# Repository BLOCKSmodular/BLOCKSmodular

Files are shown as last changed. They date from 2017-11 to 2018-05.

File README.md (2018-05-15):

# BLOCKSmodular
**WORK IN PROGRESS**  
This is work in progress. Please use it at your own risk.  

BLOCKSmodularはROLI BLOCKSとモジュラーシンセサイザーとを連携させることからはじまった、新しい音楽インターフェース/音楽表現を考えるプロジェクトです。  
開発はオープンソースで進められており、ソースコード、筐体や基板設計データをライセンスの範囲内において自由に利用できます。  
[プロジェクトサイト](https://blocksmodular.github.io/)にはBLOCKSmodularを使用したパフォーマンス映像などもアップされています。  

## Feature
- 8ch CV output  
- 4ch Gate output  
- 2ch Audio output  

## LICENSE
GPL v3

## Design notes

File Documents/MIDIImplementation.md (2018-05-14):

# MIDI Implementation
##モード切り替え
| Mode | MIDI CC | Value | MIDI Channel |
| :--- | :--- | :---- | :--- |
| Init | 1 | 0 | 16(MIDI: 0xBF) |
| Granular synthesis | 1 | 1 | 16(MIDI: 0xBF) |
| Sample playback | 1 | 2 | 16(MIDI: 0xBF) |
| Karplus strong | 1 | 3 | 16(MIDI: 0xBF) |
| Logistic map | 1 | 4 | 16(MIDI: 0xBF) |
| Sine circle map | 1 | 5 | 16(MIDI: 0xBF) |
| Morph looper | 1 | 6 | 16(MIDI: 0xBF) |
| Microtonal | 1 | 7 | 16(MIDI: 0xBF) |
| Euclid | 1 | 8 | 16(MIDI: 0xBF) |

## モード詳細
### Granular synthesis
| Description | MIDI CC | Value | MIDI Channel |
| :--- | :--- | :---- | :--- |
| X: Sample start position  | 1, 2 | 14bit | 1~4 |
| Y : Grain size | 3, 4 | 14bit | 1~4 |
| Z : Window function shape | 5, 6 | 14bit | 1~4 |

### Sample playback
| Description | MIDI CC | Value | MIDI Channel |
| :--- | :--- | :--- | :--- |
| Transpose(Play/Stop) | 1 | 0(stop)/127(play) | 1~4 |

### Karplus strong
| Description | MIDI CC | Value | MIDI Channel |
| :--- | :--- | :---- | :--- |
| Distance: Pitch | 1, 2 | 14bit | 1~4 |
| Z(Pressure): Decay | 3, 4 | 14bit | 1~4 |
| Touch start: trigger | 5 | 127 | 1~4 |

### Logistic map
| Description | MIDI CC | Value | MIDI Channel |
| :--- | :--- | :---- | :--- |
| Distance: Logistic map alpha | 1, 2 | 14bit | 1 |
| Z(Pressure): Volume | 3, 4 | 14bit | 1 |
| Distance: Sine circle map alpha | 1, 2 | 14bit | 2 |
| Z(Pressure): Volume | 3, 4 | 14bit | 2 |

### Morph looper
| Description | MIDI CC | Value | MIDI Channel |
| :--- | :--- | :--- | :--- |
| Rec | 1 | 0(End)/127(Begin) | 1, 2 |
| Play | 2 | 0(Stop)/127(Play) | 1, 2 |
| X | 3, 4 | 14bit | 1, 2 |
| Y | 5, 6 | 14bit | 1, 2 |
| Z | 7, 8 | 14bit | 1, 2 |

*Note*
| Description | Note number | Value | MIDI Channel |
| :--- | :--- | :--- | :--- |
| Clear | 1 | Note on | 1, 2 |

### Microtonal
| Description | MIDI CC | Value | MIDI Channel |
| :--- | :--- | :---- | :--- |
| Distance | 1, 2 | 14bit | 1~4 |
| Z | 3, 4 | 14bit | 1~4 |

### Euclid sequence

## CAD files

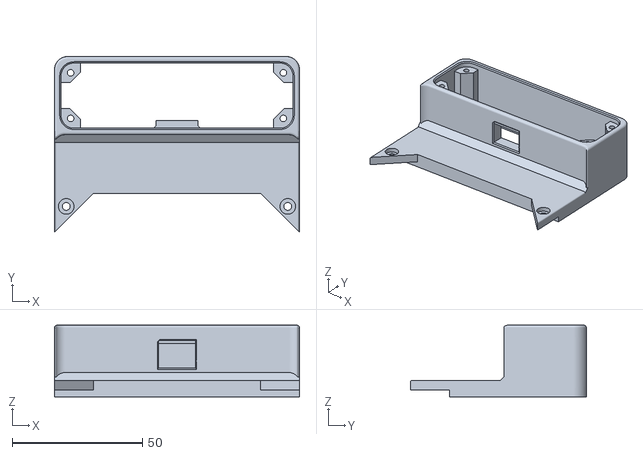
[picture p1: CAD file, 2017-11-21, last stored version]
Prototype/v0.5.0/body/blocksmodularv3.0 v2_top v2_2.stl
94.0 x 67.5 x 27.5

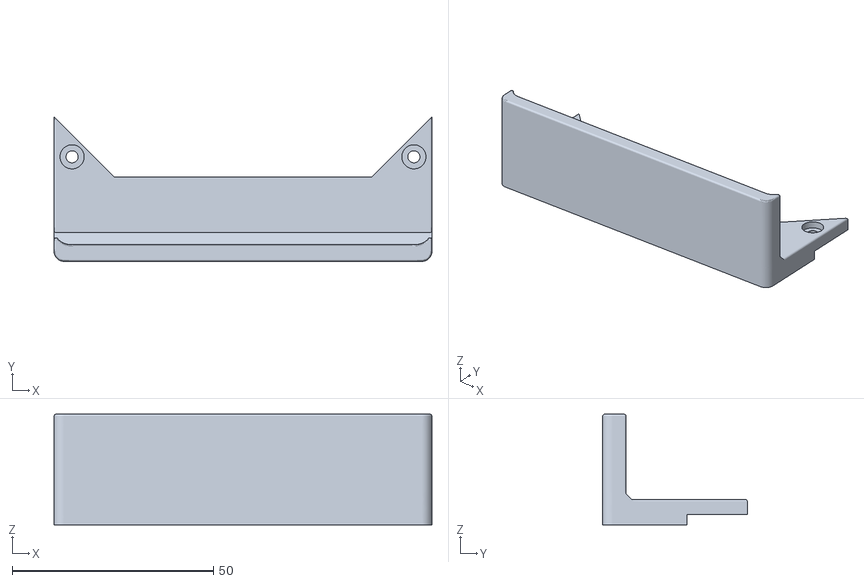
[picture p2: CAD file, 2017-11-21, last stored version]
Prototype/v0.5.0/body/blocksmodularv3.0 v2_bottom v2 v1.stl
94.0 x 36.0 x 27.5

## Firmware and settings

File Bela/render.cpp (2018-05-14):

/*
 BLOCKSmodular ver0.7.0
 render.cpp for BLOCKSmodular
 Created by Akiyuki Okayasu
 License: GPLv3
 */
#include <Bela.h>
#include <Midi.h>
#include <stdlib.h>
#include <cmath>
#include <atomic>
#include <vector>
#include <random>
#include <SampleBuffer.h>
#include <Util.h>
#include <GranularSynth.h>
#include <LogisticMap.h>
#include <SineCircleMap.h>
#include <KarplusStrong.h>

enum class ModeList{
    init = 0,
    Granular,
    SamplePlay,
    Karplus,
    Logistic,
    SineCircle,
    MorphLooper,
    Microtonal,
    Euclid
};

static constexpr int NUMCVOUT = 8;
static constexpr int NUMSAMPLEPLAYBUFFER = 4;
static constexpr int NUMKARPLUSVOICE = 4;
static constexpr int NUMMICROTONALVOICE = 4;
Midi midi;
ModeList mode;
const char *gMidiPort0 = "hw:1,0,0";

LogisticMap logisticOsc;
HighResolutionControlChange	lgst_alpha;
HighResolutionControlChange lgst_gain;
SineCircleMap sineCircleOsc;
HighResolutionControlChange sineCircle_k;
HighResolutionControlChange sineCircle_gain;
GranularSynth granular;
HighResolutionControlChange gr_Position[2];
HighResolutionControlChange gr_GrainSize[2];
HighResolutionControlChange gr_WindowShape[2];
HighResolutionControlChange microtone_Distance[NUMMICROTONALVOICE];
HighResolutionControlChange microtone_Pressure[NUMMICROTONALVOICE];
StereoBuffer* samplePlay_buffer;
bool samplePlay_isPlaying[NUMSAMPLEPLAYBUFFER]{false, false, false, false};
KarplusStrong karplus[NUMKARPLUSVOICE];
HighResolutionControlChange kp_pitch[NUMKARPLUSVOICE];
HighResolutionControlChange kp_decay[NUMKARPLUSVOICE];
Smoothing CVSmooth[NUMCVOUT];

void midiMessageCallback(MidiChannelMessage message, void *arg)
{
    const int channel = message.getChannel();//MIDIChannel(0~15)
    if(message.getType() == kmmControlChange)//MIDI CC
    {
        const int controlNum = message.getDataByte(0);
        const int value = message.getDataByte(1);
        //std::cout<<channel<<", "<<controlNum<<", "<<value<<std::endl;
        
        switch(mode) {
            case ModeList::init: {
                std::cout<<"mode init..."<<std::endl;
                break;
            }
            case ModeList::Granular: {
                if(channel >= 2)
                {
                    break;
                }
                
                if(controlNum == 1 || controlNum == 2) {
                    bool isUpeerByte{controlNum == 1};
                    gr_Position[channel].set(value, isUpeerByte);
                    if(gr_Position[channel].update()) granular.setBufferPosition(gr_Position[channel].get(), channel);
                }
                
                if(controlNum == 3 || controlNum == 4) {
                    bool isUpeerByte{controlNum == 3};
                    gr_GrainSize[channel].set(value, isUpeerByte);
                    if(gr_GrainSize[channel].update()) granular.setGrainSize(gr_GrainSize[channel].get(), channel);
                }
                
                if(controlNum == 5 || controlNum == 6) {
                    bool isUpeerByte{controlNum == 5};
                    gr_WindowShape[channel].set(value, isUpeerByte);
                    if(gr_WindowShape[channel].update()) {
                        float v = gr_WindowShape[channel].get() * 2.0f;
                        granular.setWindowShape(v * 4.0f, channel);
                        granular.setDensity((v * v * v), channel);
                    }
                }
                
                break;
            }
            case ModeList::SamplePlay: {
                if(channel >= NUMSAMPLEPLAYBUFFER)
                {
                    break;
                }
                
                if(controlNum == 1) {
                    if(value == 127) {
                        samplePlay_buffer[channel].setReadIter(0);
                        samplePlay_isPlaying[channel] = true;
                    }
                }
                
                break;
            }
            case ModeList::Karplus: {
                if(channel >= NUMKARPLUSVOICE)
                {
                    break;
                }
                
                if(controlNum == 1 || controlNum == 2) {
                    bool isUpeerByte{controlNum == 1};
                    kp_pitch[channel].set(value, isUpeerByte);
                    if(kp_pitch[channel].update()) {
                        const float p = kp_pitch[channel].get() * 40.0f + 40.0f;//40Hz~80Hz
                        karplus[channel].setFreq(p);
                    }
                }
                
                if(controlNum == 3 || controlNum == 4) {
                    bool isUpeerByte{controlNum == 3};
                    kp_decay[channel].set(value, isUpeerByte);
                    if(kp_decay[channel].update()) karplus[channel].setDecay(kp_decay[channel].get());
                }
                
                if(controlNum == 5 && value == 127) {
                    karplus[channel].trigger();
                }
                
                break;
            }
            case ModeList::Logistic: {
                if(channel == 0) {
                    if(controlNum == 1 || controlNum == 2) {
                        bool isUpeerByte{controlNum == 1};
                        lgst_alpha.set(value, isUpeerByte);
                        if(lgst_alpha.update()) logisticOsc.setAlpha(lgst_alpha.get() * 0.5f + 3.490f);
                    }
                    
                    if(controlNum == 3 || controlNum == 4) {
                        bool isUpeerByte{controlNum == 3};
                        lgst_gain.set(value, isUpeerByte);
                        if(lgst_gain.update()) logisticOsc.setGain(lgst_gain.get());
                    }
                }
                else if(channel == 1) {
                    if(controlNum == 1 || controlNum == 2) {
                        bool isUpeerByte{controlNum == 1};
                        sineCircle_k.set(value, isUpeerByte);
                        if(sineCircle_k.update()) sineCircleOsc.setK(sineCircle_k.get() * 0.2f + 1.0f);
                    }
                    
                    if(controlNum == 3 || controlNum == 4) {
                        bool isUpeerByte{controlNum == 3};
                        sineCircle_gain.set(value, isUpeerByte);
                        if(sineCircle_gain.update()) sineCircleOsc.setGain(sineCircle_gain.get());
                    }
                }
                break;
            }
            case ModeList::SineCircle: {
                //TODO SineCircleMapモードの実装
                break;
            }
            case ModeList::MorphLooper: {
                break;
            }
            case ModeList::Microtonal: {
                if(channel >= NUMMICROTONALVOICE) {
                    std::cout<<"MIDI: Invalid voice number"<<std::endl;
                    break;
                }
                
                if(controlNum == 1 || controlNum == 2) {
                    bool isUpeerByte{controlNum == 1};
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

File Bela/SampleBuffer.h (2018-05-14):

/*
 SampleBuffer.h for BLOCKSmodular
 Created by Akiyuki Okayasu
 License: GPLv3
 */

#ifndef SAMPLEBUFFER_H_
#define SAMPLEBUFFER_H_

#include <Bela.h>
#include <sndfile.h>// to load audio files
#include <string>
#include <iostream>
#include <cstdlib>
#include <vector>
#include <Util.h>
#include <atomic>

class MonoBuffer {
public:
    MonoBuffer(const int size, bool loopPlaying = false, bool loopRecording = false)
    :readLoop(loopPlaying), writeLoop(loopRecording)
    {
        buffer.resize(size);
        bufferSize = size;
    }
    
    ~MonoBuffer(){}
    
    void resize(const int size)
    {
        buffer.resize(size, 0.0f);
        bufferSize = size;
    }
    
    void nextBlock(float* bufferToWrite, const int blockSize)
    {
        for(int i = 0; i < blockSize; ++i)
        {
            bufferToWrite[i] += buffer[readIter];
            addReadIter(1);
        }
    }
    
    const float* getReadPtr()
    {
        return buffer.data();
    }
    
    float* getWritePtr()
    {
        return buffer.data();
    }
    
    int getSize()
    {
        return bufferSize;
    }
    
    const unsigned int getWriteIter()
    {
        return writeIter;
    }
    
    const unsigned int getReadIter()
    {
        return readIter;
    }
    
    void readNext(float& value)
    {
        if(readIter < bufferSize)
        {
            value += buffer[readIter];
            addReadIter(1);
        }
    }
    
    void writeNext(float& value)
    {
        buffer[readIter] = value;
        addWriteIter(1);
    }
    
    void addReadIter(const unsigned int add)
    {
        if(readIter + add >= bufferSize && !readLoop) {
            readIter = bufferSize;
            return;
        }
        
        readIter += add;
        if(readIter >= bufferSize) {
            readIter -= bufferSize;
        }
    }
    
    void addWriteIter(const unsigned int add)
    {
        if(writeIter + add >= bufferSize && !writeLoop) {
            writeIter = bufferSize;
            return;
        }
        
        writeIter += add;
        if(writeIter >= bufferSize) {
            writeIter -= bufferSize;
        }
    }
    
    void setReadIter(const unsigned int itr) {
        if(itr < buffer.size()) {
            readIter = itr;
        }
        else{
            std::cout<<"MonoBuffer-setReadIter(): Invalid iterater"<<std::endl;
        }
    }
    
    void loadSampleFile(std::string file)
    {
        SNDFILE *sndfile ;
        SF_INFO sfinfo ;
        sfinfo.format = 0;
        if (!(sndfile = sf_open (file.c_str(), SFM_READ, &sfinfo))) {
            std::cout << "Couldn't open file " << file << ": " << sf_strerror(sndfile) << std::endl;
            return;
        }
        
        int numChannelsInFile = sfinfo.channels;
        
        if(numChannelsInFile != 1)//1chのファイルのみ許可
        {
            std::cout << "Error: " << file << " doesn't contain requested channel" << std::endl;
            return;
        }
        
        const int frameLen = getNumFrames(file);
        if(buffer.size() < frameLen) {
            std::cout << "Warning: MonoBuffer class was resized!!!" << std::endl;
            buffer.resize(frameLen, 0.0f);
            bufferSize = frameLen;
        }
        
        sf_seek(sndfile,0,SEEK_SET);
        float* tempBuf = new float[frameLen*numChannelsInFile];
        int subformat = sfinfo.format & SF_FORMAT_SUBMASK;
        int readcount = sf_read_float(sndfile, tempBuf, frameLen*getNumChannels(file)); //FIXME
        
        // Pad with zeros in case we couldn't read whole file
        for(int k = readcount; k <frameLen*numChannelsInFile; k++)
            tempBuf[k] = 0;
        
        if (subformat == SF_FORMAT_FLOAT || subformat == SF_FORMAT_DOUBLE)
        {
            double	scale ;
            int 	m ;
            
            sf_command (sndfile, SFC_CALC_SIGNAL_MAX, &scale, sizeof (scale)) ;
            if (scale < 1e-10)
                scale = 1.0 ;
            else
                scale = 32700.0 / scale ;
            std::cout << "File samples scale = " << scale << std::endl;
            
            for (m = 0; m < frameLen; m++)
                tempBuf[m] *= scale;
        }
        
        for(int n=0;n<frameLen;n++)
        {
            buffer[n] = tempBuf[n*numChannelsInFile];
            /*Streeo buffer and Stereo file
             buffer[n][0] = tempBuf[n*numChannelsInFile + 0];
             buffer[n][1] = tempBuf[n*numChannelsInFile + 1];
             */
        }
        
        sf_close(sndfile);
    }
    
private:
    std::vector<float> buffer;
    std::atomic<unsigned int> readIter{0};
    std::atomic<unsigned int> writeIter{0};
    unsigned int bufferSize;
    bool readLoop;
    bool writeLoop;
};
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

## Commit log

2017-10-16 [add] Maxパッチを追加
2017-10-17 筐体データ
2017-10-17 Initialize Arduino - convert serial values to CV - convert PWM to Analog signal
2017-10-20 [remove] OSC送信部分を削除
    Raspberry piへOSCを送ることを想定していたが、しばらく着手しないので削除。
    他オブジェクトの整列。コメント追加も適宜行なっている。
2017-10-20 [remove] Seaboard BLOCKからMIDI受信部分を削除
    トランスポートの管理、シリアル通信、LightpadのUI部分をきちんと詰めてから、Seaboard BLOCKに着手することにする
2017-10-20 [update] シリアル通信部分を改良
    CV出力ごとにセパレータをつけて送っていたが、通信量多くなり、順番の保証もされない懸念があった。
    全てのCV出力のデータを同時に送信することで通信量削減と順番の保証をした。
    具体的には
    CV1前半8bit, 後半8bit, CV2前半8bit, 後半8bit, CV3前半8bit, 後半8bit, CV4前半8bit, 後半8bit
    のリストを送信している。
2017-10-20 筐体データ修正
2017-10-22 [update] シリアル通信の仕様を改善
    CV出力を8つに増やした。
    シリアルで送信するリストのプリフィックスはhとした。
    送信するリストはこのようになった。
    [h, cv1上位8bit, cv1下位8bit, cv2上位8bit, cv2下位8bit, cv3上位8bit, cv3下位8bit, cv4上位8bit, cv4下位8bit, cv5上位8bit, cv5下位8bit, cv6上位8bit, cv6下位8bit, cv7上位8bit, cv7下位8bit, cv8上位8bit, cv8下位8bit]
    またシリアルのデータ転送レートを115200bpsに変更。
2017-10-25 [update] blocks.looper~の代わりにbuffer~でLightpadの動きの記録をさせる
    blocks.looper~を複数個同時使用すると不安定になっていたのでbuffer~で同じ機能を作る
2017-10-25 [remove] ルーパー機能の置き換えに伴ってこれまでの制御部分を削除
2017-10-29 [add] XYZの動きを記録しループするLittlefootのプログラムを追加
2017-10-30 [update] MaxパッチにRec開始を伝えるためのフラグ機能を整理
2017-10-30 [add] コメントを追加
    state(セッションビュー画面/XYZパッドなどの状態)に関するコメントを追加。
2017-10-30 [add] 録音/再生状態による条件分岐を追加
    トランスポート管理用の条件分岐。
2017-10-30 [add] MIDI受信ハンドラを追加
    MIDI受信するハンドラを準備しただけ。
    MIDI受信の内容によってrecクリアなどの機能を割り当てる予定。
2017-10-30 [update] Maxパッチの軽微な変更。
    オブジェクトの位置調整などで変更が加えられてしまったのでコミット。
    Littlefootプログラムが落ち着いたらMaxパッチも大規模な変更を加える予定なので、今回の変更に意味はない。
2017-11-03 [add] MorphLooperのControl Block用のLittlefootプログラムを追加
2017-11-03 [update] シンプルなルーパー(サブパッチ)
2017-11-03 [update] シンプルなルーパーサブパッチ
2017-11-03 [update] MIDIチャンネル選択のを0~15の範囲に変更
    0:1ch
    1:2ch
    の要領でMIDIチャンネルを指定する
2017-11-03 [update] 各トラックの録音/再生フラグ、XYZ座標をMaxパッチと通信することに成功
2017-11-03 [update] コメントが分かりづらかったので文面修正
2017-11-03 [update] ルーパー機能は完成
    シリアル通信とBLOCKSへのMIDI送信機能はこれから。
2017-11-03 [add] MaxパッチからXYZ座標情報(MIDI CC)を受け取りプレッシャーマップを表示する
    Max側で記録した指の動きをBLOCKにMIDI CCで送信することでプレッシャーマップの再現に成功。
2017-11-03 [update] シリアル通信機能が完成
2017-11-03 [add] Developer Control Blocksの0~3ボタンで録音消去をできるようにした
    Develop Control Blockのボタンを押すとMaxへMIDI CCが送られ、buffer~をクリアする。その後MaxからBLOCKSの録音/再生フラグをオフにさせるためのMIDI CCが送られる。
    ボタン0:トラック1録音消去
    ボタン1:トラック2録音消去
    ボタン2:トラック3録音消去
    ボタン3:トラック4録音消去
2017-11-04 [update] プレッシャーマップ表示を調整
2017-11-04 [update] Maxパッチ更新
2017-11-04 [add] ポリフォニック(最大4音)微分音演奏モードを追加
    LittllefootとMaxパッチを追加
2017-11-07 [update] 微分音オルガンモードの基本となるCC番号を96に変更
    MorphLooperとの統合を考慮してMIDIの割り当てを行なった。
2017-11-07 [remove] littlefootのデフォルトModeを間違って作成してしまっていたのを削除
2017-11-07 [update] 微分音オルガンの出力をゲートではなくプレッシャーに変更
    1つの指につき
    ピッチ(Lightpad中心点からの距離)
    ノートオン/オフ
    の出力をしていたが、ノートオン/オフをプレッシャーに変更。
2017-11-07 [add] MIDIの規則についてのマークダウン書類を追加
    MIDI noteやCCの番号分けについての資料。
2017-11-07 [update] 微分音オルガン用Maxパッチの微細な変更
    MIDIデータの補間の調整やオブジェクトの細かい位置調整など。
2017-11-10 [update] cvテスト用のスケッチを追加
2017-11-11 [update]動作確認用スケッチの作成
    - マックスのテストパッチでシリアル番号の受け取りと出力のテスト用ツール
    - ボード一枚でそれぞれテスト済み
2017-11-12 [update]11/11実機動作確認済ver
    11/11実機動作確認済ver
2017-11-12 [remove] 余計なコメントアウトを削除
2017-11-12 [update] シリアルの送信感覚を40ms間隔で一定にする
2017-11-12 [update] MicrotonalBlockのシリアル送信間隔を30msに設定
    速すぎると上手く通信できないので30msに設定した。
2017-11-12 [update] MorphLooperのシリアルとMIDI送信間隔の調整
2017-11-13 [update] シリアルのボーレートを57600に下げる
    115200だと不安定なので57600に下げた。
2017-11-13 [remove] concatValues()とcvOut2channel()を削除
2017-11-13 [update] シリアル通信の規則を変更
    1つのCVにつき2byteのデータを送信する。
    上位4bitをCV出力チャンネル選択のフラグとして利用し、下位12bitをCVの値(0~4095->0V~10V)とする。
2017-11-13 [update] 最新のシリアル通信規則に合わせてMaxパッチを変更
    通信量と読み取り速度が一定になるようにした。
2017-11-13 [fix] シリアルが2バイト以上たまっているときはwhile文で回すように変更
    たとえ4バイトたまっていても2バイトしか受け取らないようになっていた。高速に大量のデータを受信すると受け取りきれない可能性があった。
    while文を回して全て受け取るように変更した。
2017-11-14 [add] 入力データにローパスをかける処理を追加
    RCフィルタのローパス。
2017-11-14 [update] MIDI規則を更新
    MIDI CCを2つ使って14bitデータをBLOCKSから送信する。
2017-11-15 [fix] シリアルを落とした時に順番を復旧させられるような処理を追加
    2バイトで1セットなので順番が変わってしまうとめちゃくちゃな値になってしまう。ヘッダーの値をみて条件分岐させることで復旧させる。
2017-11-15 [update] CCを2使って14bitのデータを送信させる
    7bitだと足りないので14bitにした。
2017-11-15 [update] シリアルの負荷軽減のために通信量が上下しないようにした
2017-11-15 [add] シリアル規則を記載するためのマークダウンファイルを追加
2017-11-15 [update] シリアル通信の規則を更新
2017-11-15 [update] Arduinoのコードに最新のシリアル通信規則を適用した
2017-11-16 [add] ビット演算用Maxサブパッチを追加
    11bitのデータを上位4bitと下位7bitに分割する
2017-11-16 [update] Maxパッチを最新のシリアル規則に合わせた
2017-11-16 [add] 下位バイトのフラグ判定を追加
2017-11-16 [add] MIDI規則にモード切り替え用MIDIノートを追加
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2017-11-16 [fix] MorphLooperの録音クリアを二度叩いてしまう問題を修正
    CCが0になったときもクリアしていたので、127のときのみクリアするようにした。
2017-11-16 [fix] MIDI規則の間違いを修正
    録音クリアはCCで送っているのにNoteとして記載してしまっていた。
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2017-11-16 [fix] 再生停止時にもプレッシャーマップの情報を送りつづけてしまっていた問題を修正
    changeオブジェクトの位置に間違いがあったので修正。
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2017-11-16 [fix] 正しくモードが切り替わらない問題を修正
2017-11-16 [fix] MicrotonalBLOCKモード切り替え時にMorphLooperの再生が止まらない問題を修正
2017-11-16 [fix] シリアル通信がきちんとできたバージョン
2017-11-16 [fix] コメントの間違いを修正
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2017-11-16 [fix] 音が鳴り止まないバグを修正
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2017-11-16 [fix] モード選択のバグを修正
2017-11-16 [fix] モード切り替えができない問題を修正
2017-11-21 [add] 筐体データ更新＆旧データ消した
    [blocksmodularv3.0 v2_bottom v2 v1.stl, blocksmodularv3.0 v2_top v2_2.stl]
2017-11-21 Revert "[add] 筐体データ更新＆旧データ消した"
    This reverts commit 37e77050772a151807364431a969dd7132c4ee59.
    [blocksmodularv3.0 v2_bottom v2 v1.stl, blocksmodularv3.0 v2_top v2_2.stl]
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2018-01-26 リポジトリの整理
    TFoM2017用プロトのソースは別フォルダでまとめる
    [blocksmodularv3.0 v2_bottom v2 v1.stl, blocksmodularv3.0 v2_top v2_2.stl]
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2018-01-26 [add] BLOCKS codeのプロジェクトファイルを追加
    ROLI製Littlefootエディタを使用するときはプロジェクトファイルが必要になるようなので追加。
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2018-01-26 [fix] セミコロンをつけるのを忘れたので修正
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2018-03-08 [add] SampleBuffer.hにバッファーの書き換え不可ポインタ取得関数を追加
    const float*が返る関数。
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2018-03-18 [update] GranularSynthの内部クラスGrainから親クラスにアクセスできるように変更
    GrainクラスにGranularSynthクラスの参照を持たせることでGranularSynthクラスの関数や変数にアクセスできるようにした。
    グレインサイズや波形選択範囲などはGranularSynthクラスで管理する。
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2018-03-18 [fix] グラニュラークラスのloadBuffer()とloadFile()使用直後にバッファーの範囲外アクセスが発生する可能性があった
    loadBuffer()とloadFile()で各グレインの初期化処理を足すことで解消した。
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2018-03-26 [fix] BLOCKSから送信したMIDIのチャンネルが正しくない問題を修正
2018-03-26 [fix] Smoothingクラスの簡単な間違いの修正
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2018-03-30 [fix] グレインのIDが正しく初期化されない問題を修正
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2018-03-30 [fix] HighResolutionControlChangeの値変更したかの判定が正しくない問題を修正
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2018-03-31 タイポ修正
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2018-03-31 [fix] グレイん初期値計算の間違いを修正
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2018-03-31 [fix] 可変窓関数が矩形窓に近づかない問題を修正
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2018-04-07 [fix] littlefootのMIDIチャンネルがずれている問題を修正
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2018-04-08 [fix] Microtonal時に3本指で触れるとクラッシュする問題を修正
2018-04-08 [remove] CVModeOFF, AudioModeOFF, isCVModeなどの不要なコメントアウトを削除
2018-04-08 [fix] MIDIチャンネルの数え方がずれていた問題を修正
2018-04-08 [fix] Microtonalのチャンネル間違いでCVが正しく出なかった問題を修正
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2018-04-09 [fix] SamplePlaybackのときはtouchMoveのときにMIDIを送信しない
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2018-04-10 Fix: SamplePlaybackのMIDIチャンネルを間違えて送っていた問題を修正
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2018-04-11 Fix: サンプルロード後にbufferSize変数が正しくない問題を修正
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2018-04-12 Fix: オーディオ/CV切替スイッチの極性を変数名を合わせる
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2018-04-14 Fix: ノイズの音量が小さい問題を修正
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2018-04-19 Fix: ポインタの配列を削除するときにクラッシュする問題を修正
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2018-04-21 Fix: Littlefootのインデックスのずれを修正
2018-04-21 Fix:チャンネル数の外のMIDIも受けてしまうバグを修正
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2018-05-14 Remove: v0.5.0で使用していたファイルを削除
    現行のv0.7.0では使用しないファイルのため削除。
    [blocksmodularv3.0 v2_bottom v2 v1.stl, blocksmodularv3.0 v2_top v2_2.stl]
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
